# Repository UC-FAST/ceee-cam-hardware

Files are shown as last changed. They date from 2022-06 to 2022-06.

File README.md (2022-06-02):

# ceee-cam-hardware

# 硬件
## 我需要准备什么
* 学硬件是要烧钱的，为了完成这个项目，1000元是可能需要花费的。
* 需要购买的成品组件：
    - 树莓派HQ摄像头模组
    - 一个C或者CS接口的镜头，1/23"以上面积
    - 树莓派Zero 2w
* 必须的工具：电烙铁、热风枪、焊锡、锡浆、镊子等
* 基本的电路板绘制技能
* 一些其他零件：在文件BOM.xlsx内
* 若干电阻以及电容等，参照原理图
_____
## 需要自制的电路板组件
本项目内含四块需要自制的电路板，分别为：
* Z01-2：电源板，负责整个系统的充放电，附带电量指示功能，并提供基本的输入按钮
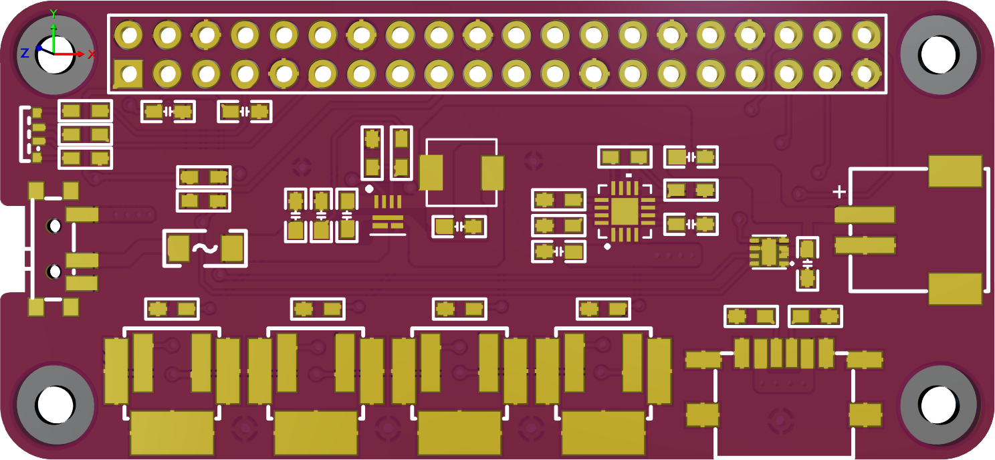
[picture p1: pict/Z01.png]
电源板 Z01

* Z02：摄像头转接板及支架，这一部分是作为结构板、不含电路的
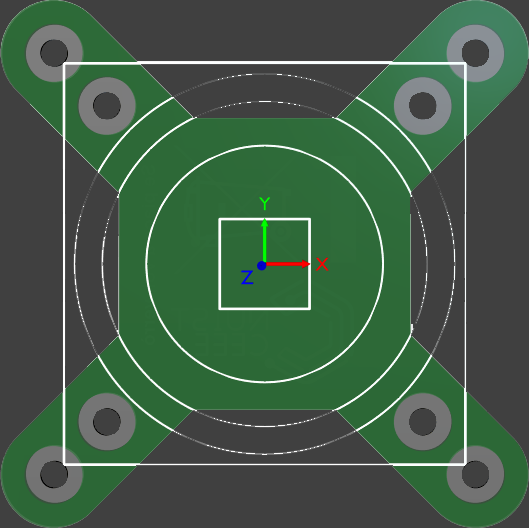
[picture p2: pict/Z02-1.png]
转接板 摄像头转接板

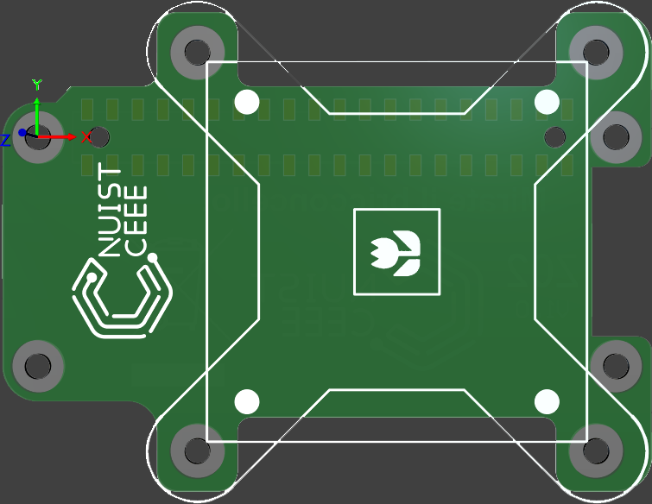
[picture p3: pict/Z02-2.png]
支架 摄像头支架

* Z03：Lcd显示屏板，附带一个5D开关
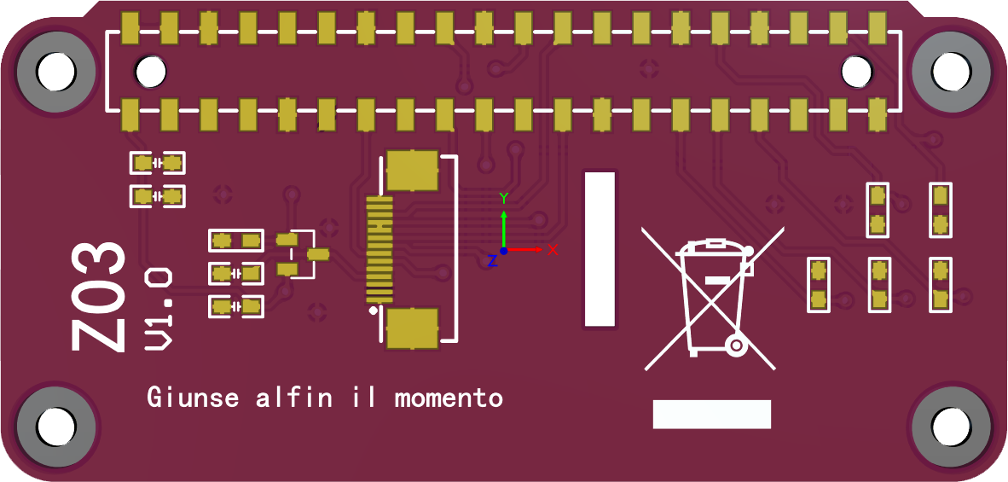
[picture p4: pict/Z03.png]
Lcd显示屏板


____

## 组装
需要用到若干5mm尼龙柱、10mm尼龙柱、12mm尼龙柱、15mm尼龙柱、M2.5尼龙螺丝以及M2.5尼龙螺母。本项目中所有安装孔都是2.5mm的直径。

### 组装顺序：
|层数|名称|高度（尼龙柱长度，单位mm）|
|-|-|-|
|1|树莓派HQ摄像头模组|
||尼龙柱|5|
|2|摄像头转接板 Z02||
||尼龙柱|5|
|3|摄像头支架 Z02|
||尼龙柱|10|
|4|树莓派Zero 2w，焊接17mm双排针|
||尼龙柱|12或15|
|5|电源板 Z01-2|
||尼龙柱|12|
|6|Lcd显示屏板|

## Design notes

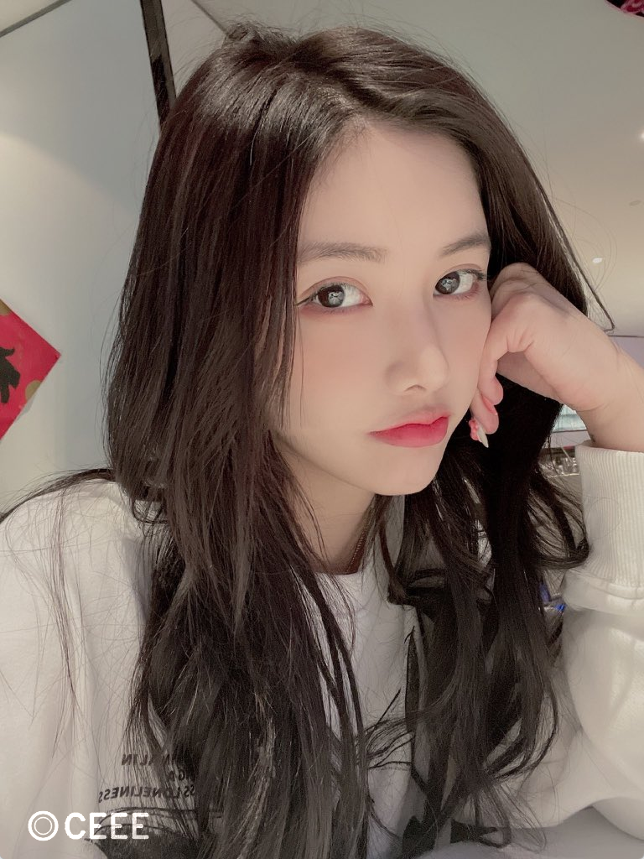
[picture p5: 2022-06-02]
pict/WaterMark.png

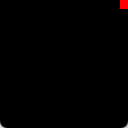
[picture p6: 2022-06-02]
pict/Busy.png

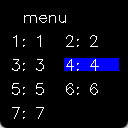
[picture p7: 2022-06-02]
pict/DialogBox.png

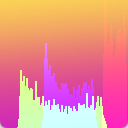
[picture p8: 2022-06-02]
pict/Hist.png

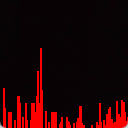
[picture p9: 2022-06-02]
pict/BarChart.png

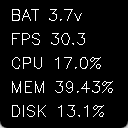
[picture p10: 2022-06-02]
pict/SimpleText.png

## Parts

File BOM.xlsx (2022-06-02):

序号 | 名称 | 链接 | 备注
 | L6924D | https://item.szlcsc.com/166977.html | 可选其他平台同型号
 | TPS61230A | https://item.szlcsc.com/348561.html | 可选其他平台同型号
 | 1A自恢复保险丝 | https://item.szlcsc.com/343074.html | 可选其他平台，视情况可选其他规格
 | USB TYPEC | https://item.szlcsc.com/763637.html | 可选其他平台同型号
 | MAX17048 | MAX17048G+T10_（MAXIM(美信)）MAX17048G+T10中文资料_价格_PDF手册-立创电子商城 (szlcsc.com) (https://item.szlcsc.com/2777647.html) | 可选其他平台同型号
 | 5D SWITCH | TM-2027_（XKB Connectivity(中国星坤)）TM-2027中文资料_价格_PDF手册-立创电子商城 (szlcsc.com) (https://item.szlcsc.com/300040.html) | 可选其他平台同型号
 | FPC连接器 | AFC07-S14FCA-00_（JS(钜硕电子)）AFC07-S14FCA-00中文资料_价格_PDF手册-立创电子商城 (szlcsc.com) (https://item.szlcsc.com/253870.html) | 可选其他平台同参数型号
 | 电容10uF | CC0603KRX5R6BB106_（YAGEO(国巨)）CC0603KRX5R6BB106中文资料_价格_PDF手册-立创电子商城 (szlcsc.com) (https://item.szlcsc.com/306274.html) | 可选其他平台同参数型号
 | 电容22uF | TAJB226K016TNJ_（AVX）TAJB226K016TNJ中文资料_价格_PDF手册-立创电子商城 (szlcsc.com) (https://item.szlcsc.com/417918.html) | 可选其他平台同参数型号
 | 电感 1uH | https://item.szlcsc.com/397734.html | 可选其他平台同参数型号
 | 贴片排母40p | FH-00339_（Liansheng(连盛)）FH-00339中文资料_价格_PDF手册-立创电子商城 (szlcsc.com) (https://item.szlcsc.com/2784386.html) | 可选其他平台同型号
 | 加长排针 17mm 40p | 排针间距2.54MM 2*40P 居中排针 总长 15/17/21MM 双排居中针-淘宝网 (taobao.com) (https://item.taobao.com/item.htm?spm=a1z09.2.0.0.29c72e8d3tfWbZ&id=601208054604&_u=t2oujj2ha058)
 | 加长排母40p | PC104 2.54mm2*5 2*10 2*15 2*16 2*20 2*32 2*40P 加长排母环保-淘宝网 (taobao.com) (https://item.taobao.com/item.htm?spm=a1z09.2.0.0.67002e8d6Hgtgq&id=602552664123&_u=r2oujj2hce26)
 | 尼龙柱2.5*12 | 尼龙柱M2M3M4M5双通尼龙六角柱隔离柱塑料绝缘支撑柱PC板间隔螺柱-tmall.com天猫 (https://detail.tmall.com/item.htm?id=41930274741&spm=a1z09.2.0.0.67002e8d6Hgtgq&_u=r2oujj2hcd5c)
 | 尼龙螺丝M2.5*5 | 黑色圆头尼龙螺丝盘头十字塑料螺丝塑胶元头螺钉M2M2.5M3M4M5M6M8-tmall.com天猫 (https://detail.tmall.com/item.htm?id=613863436294&spm=a1z09.2.0.0.67002e8d6Hgtgq&_u=r2oujj2hdd6e)
 | 锂电池 3.7v*1500mah | 中顺芯102050学习机骑士通牙钻便携设备仪器聚合物锂电池3.7V7.4V-淘宝网 (taobao.com) (https://item.taobao.com/item.htm?spm=a1z09.2.0.0.67002e8d6Hgtgq&id=40044501379&_u=r2oujj2h9c72) | PH2.0正向插，注意极性
 | 镜头 | 手动变焦机器视觉工业相机镜头C接口 2/3 1/2英寸 FA长焦 C口镜头-淘宝网 (taobao.com) (https://item.taobao.com/item.htm?spm=a1z09.2.0.0.67002e8d6Hgtgq&id=596496776100&_u=r2oujj2h6b45) | 任选，靶面不小于1/2.3''即可
 | IMX477 | Raspberry Pi HQ Camera树莓派高清相机 12.3MP IMX477 配CM镜头-淘宝网 (taobao.com) (https://item.taobao.com/item.htm?spm=a1z09.2.0.0.67002e8d6Hgtgq&id=616930092887&_u=r2oujj2hcf39)
 | 显示屏 | 1.44寸彩色TFT显示屏高清IPS LCD裸屏128*128 SPI接口ST7735驱动-淘宝网 (taobao.com) (https://item.taobao.com/item.htm?spm=a1z09.2.0.0.67002e8d6Hgtgq&id=665373660461&_u=r2oujj2had95)
 | 滑动开关 | MK-12C02-G015_（G-Switch(品赞)）MK-12C02-G015中文资料_价格_PDF手册-立创电子商城 (szlcsc.com) (https://item.szlcsc.com/3191561.html) | 可选其他平台同型号
 | 轻触开关 | TA3-2W2-V-T/R_（台湾圜达）TA3-2W2-V-T/R中文资料_价格_PDF手册-立创电子商城 (szlcsc.com) (https://item.szlcsc.com/513960.html) | 可选其他平台同型号
 | P沟道场效应管 | AP2301_（ALLPOWER(铨力)）AP2301中文资料_价格_PDF手册-立创电子商城 (szlcsc.com) (https://item.szlcsc.com/359128.html) | 可选其他平台同型号
 | RGB发光二极管 | FM-3510RGBA-SG_（国星光电）FM-3510RGBA-SG中文资料_价格_PDF手册-立创电子商城 (szlcsc.com) (https://item.szlcsc.com/775226.html) | 可选其他平台同型号
 | 排线 | 树莓派摄像头 软排线 FFC连接线 PI zero PI 0 摄像头连接线-淘宝网 (taobao.com) (https://item.taobao.com/item.htm?spm=a1z09.2.0.0.25c52e8dwg9Lgb&id=45533680032&_u=r2oujj2hffcd) | 4CM
